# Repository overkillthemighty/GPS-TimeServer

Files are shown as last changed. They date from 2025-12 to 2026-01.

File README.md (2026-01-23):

# ESP32 PPS Time Server

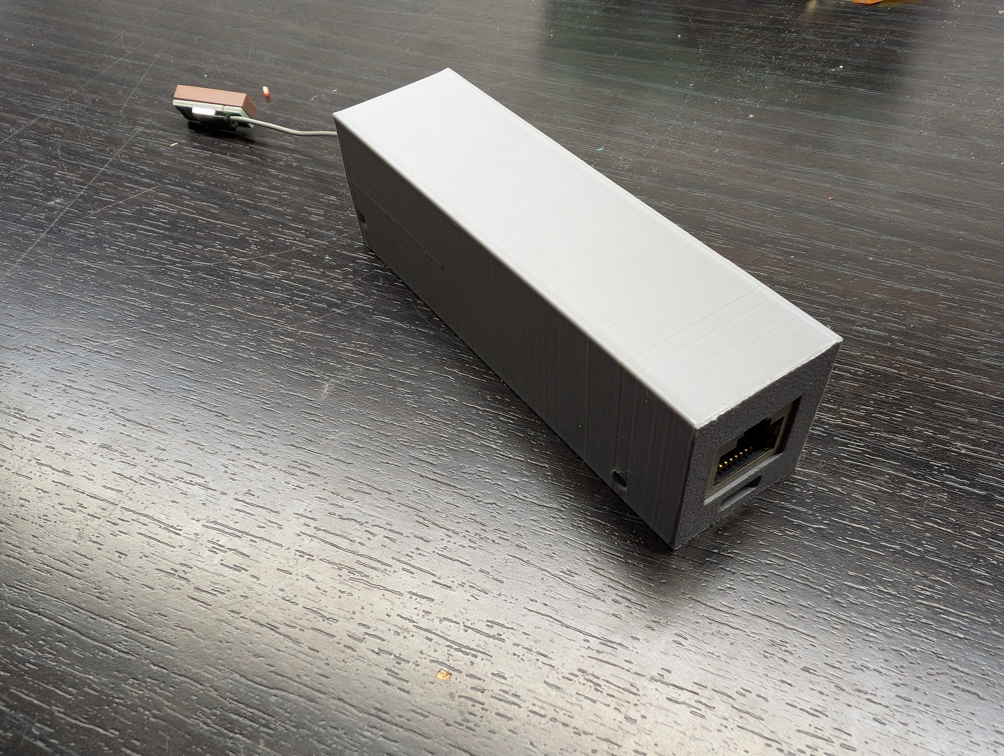
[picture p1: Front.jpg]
Assembled


I started this project when I was having trouble finding an ESP32-based PPS (Pulse Per Second) time server that compiled on a recent version of Arduino and had the features I wanted. This project provides a reliable, high-accuracy NTP server solution using an ESP32 with Ethernet support and Power over Ethernet (PoE).

## 🚀 Overview

This repository contains the firmware and 3D-printable housing for a Network Time Protocol (NTP) server. By utilizing the PPS signal from a GPS module, this server provides microsecond-level timing accuracy to your local network. 

The project is designed for the **Waveshare ESP32-S3-ETH**, but it should be easily adaptable to most ESP32 Ethernet boards and GPS modules with a PPS output.

## 🛠 Hardware Used

* **Microcontroller:** [Waveshare ESP32-S3-ETH](https://www.waveshare.com/esp32-s3-eth.htm) (Supports PoE)
* **GPS Module:** [Beitian BN-220 GPS/Glonass](https://a.co/d/dijGAva)
* **Power:** Runs directly off **PoE** via the Waveshare board, or can be powered via **USB-C**.

### Wiring Connections

| BN-220 GPS Pin | ESP32-S3-ETH Pin | Description |
| :--- | :--- | :--- |
| **VCC** | 3.3V or 5V | Power supply for GPS |
| **GND** | GND | Ground |
| **TX** | GPIO 18 (RX) | GPS Data Transmission |
| **RX** | GPIO 17 (TX) | GPS Data Reception |
| **PPS** | GPIO 2 | Pulse Per Second (High Precision) |

*Please verify these GPIO assignments in `ESP32TimeServer/ESP32TimeServer.ino` before powering on.*

## 📂 Project Structure

* **`/ESP32TimeServer`**: The Arduino sketch folder containing the source code.
* **`Case.stl`**: 3D-printable main housing for the electronics.
* **`LockBlock.stl`**: 3D-printable locking mechanism/mount.

## 🔧 Installation & Setup

1.  **Hardware:** Wire the BN-220 to the Waveshare board as shown in the table above.
2.  **Arduino IDE:** * Open `ESP32TimeServer.ino`.
    * Ensure the **ESP32 board manager** is installed (v2.0.x+).
    * Select **ESP32-S3 Dev Module** (or the specific Waveshare board profile if installed).
3.  **Flash:** Upload the code to the board via USB-C.
4.  **Enclosure:** Print the provided `.stl` files. The board is designed to snap into the case, secured by the LockBlock.

Note that I used Gemini quite a bit creating this.

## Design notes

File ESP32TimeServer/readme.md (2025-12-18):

# ESP32 MasterClock (Stratum-1 NTP via GPS PPS)

A professional-grade **ESP32-S3 + W5500** Ethernet device serving **UTC-only** NTP time as a Stratum‑1 source, disciplined by **GPS PPS**. 

This project is optimized for the **Waveshare ESP32-S3-ETH** development board and leverages the ESP32's dual-core architecture to ensure microsecond-level timing precision.

---

## 💻 Arduino IDE Configuration

To ensure compatibility with the board's 16MB Flash and PSRAM, use these exact settings in the **Tools** menu:

* **Board:** `ESP32-S3 Dev Module`
* **USB CDC On Boot:** `Enabled` (Required for the Serial Menu to work)
* **Flash Size:** `16MB (128Mb)`
* **Partition Scheme:** `16M Flash (3MB APP/9.9MB FATFS)`
* **PSRAM:** `OPI PSRAM`
* **Upload Speed:** `921600`

---

## 🚀 Key Features

### ⏱️ High-Precision Timing
- **Stratum-1 Source:** Synchronizes directly to GPS atomic clocks.
- **Dual-Core Execution:** - **Core 0:** Dedicated strictly to GPS NMEA parsing and high-priority PPS interrupt handling.
    - **Core 1:** Handles the Ethernet stack, NTP UDP requests, and the Web/Serial interfaces.
- **PPS Discipline:** RTC is corrected microsecond-by-microsecond upon every GPS pulse.

### 🌐 Networking & Reliability
- **Ethernet Only:** Wi-Fi and Bluetooth are disabled to eliminate radio-induced jitter and interrupt latency.
- **Smart Fallback:** Attempts DHCP on boot; if unsuccessful (10s timeout), falls back to the saved Static IP.
- **Serial Configuration Menu:** Full parity with the web interface for management via USB Serial.

---

## 🛠️ Hardware Setup

### Waveshare ESP32-S3-ETH Pinout
The default configuration in `ESP32TimeServerKeySettings.h` is mapped as follows:

| Component | Pin | Function |
| :--- | :--- | :--- |
| **GPS TX** | GPIO 17 | UART1 RX |
| **GPS RX** | GPIO 18 | UART1 TX |
| **GPS PPS** | GPIO 2 | Interrupt Pin |
| **ETH CS** | GPIO 14 | SPI Chip Select |
| **ETH RST** | GPIO 9 | Hardware Reset |
| **ETH IRQ** | GPIO 10 | Interrupt |

---

## ⌨️ Serial Menu Usage

Connect to the device via the Serial Monitor at **115200 baud**. Press **'h'** to see the command list:

* **`[s] Status`**: View current UTC time, GPS lock status, and satellite count.
* **`[i] Info`**: View active IP address and system uptime.
* **`[n] Network`**: **Configuration Wizard**. Use this to set Static IP, Gateway, and Subnet settings.
* **`[l] Logs`**: Dump the system event log from the internal ring buffer.
* **`[w] Wipe`**: Reset all network settings to factory defaults.
* **`[r] Reboot`**: Software restart.

---

## 📡 Required Libraries

Install these via the Arduino Library Manager:
1. `TinyGPSPlus` by Mikal Hart
2. `ESP32Time` by fbiego
3. `Time` by Paul Stoffregen

---

## 📄 License
MIT License — 2025. Created for high-reliability network time synchronization.

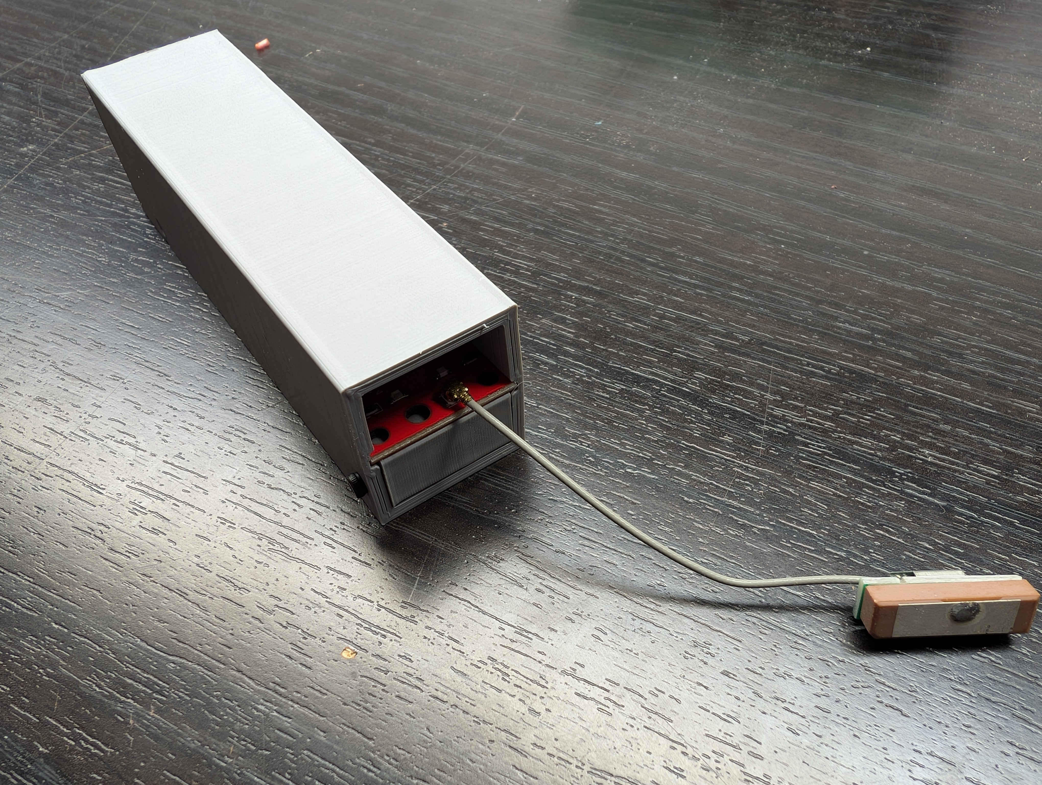
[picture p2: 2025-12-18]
Rear.jpg

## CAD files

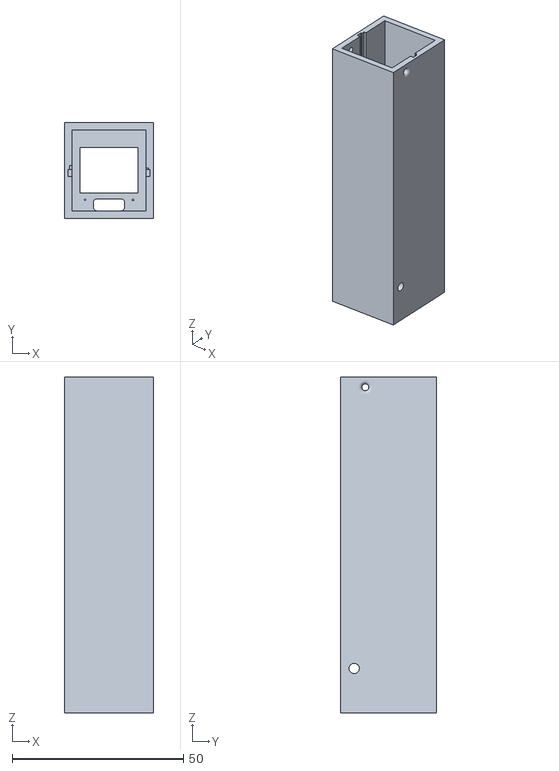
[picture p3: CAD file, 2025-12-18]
Case.stl
26.0 x 28.0 x 98.0

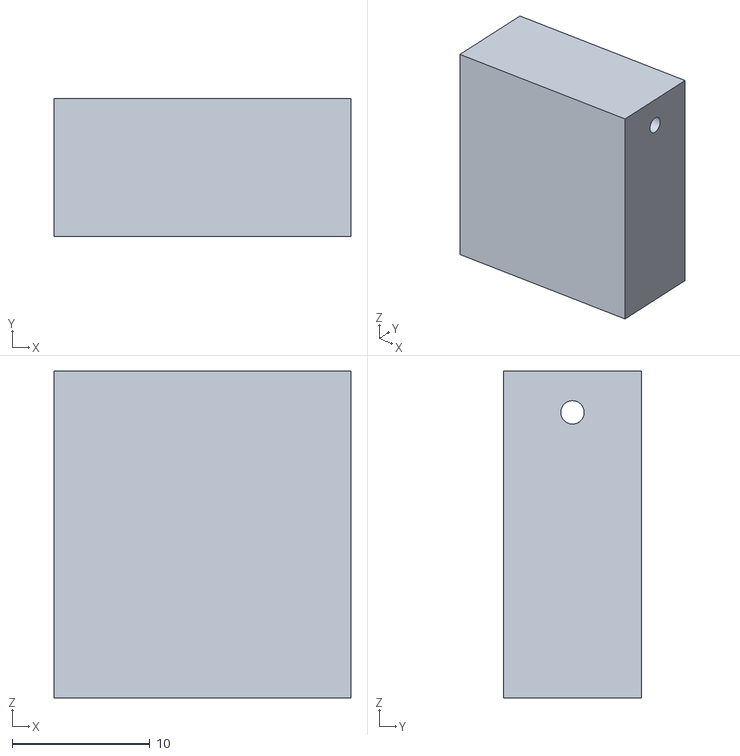
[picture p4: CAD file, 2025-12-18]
LockBlock.stl
21.5 x 10.0 x 23.7

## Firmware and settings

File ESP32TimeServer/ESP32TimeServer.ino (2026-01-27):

/*
Version 1.1
  ESP32TimeServer.ino
  MIT License — 2025

  Headless ESP32-S3 + W5500 NTP Stratum-1 server (UTC-only) using GPS PPS.

  - ETH-only (Wi-Fi and BT explicitly disabled)
  - Static IP or DHCP support
  - Serial Menu for Network Configuration (parity with Web UI)

  NTP reply fields implemented per RFC 5905 (NTPv4):
    - LI/VN/Mode = 0/4/4 when locked; LI=3, Stratum=16 when unsynchronized
    - Stratum, Poll, Precision set to sane values
    - Root Delay/Dispersion small non-zero fixed-point
    - Reference ID "GPS "
    - Timestamps (Reference/Originate/Receive/Transmit) are 64-bit:
        seconds since 1900-01-01 (NTP epoch) + 32-bit fractional part
*/
#include <ETH.h>
#include <SPI.h>
#include <WiFi.h>
#include <WiFiUdp.h>
#include <ESP32Time.h>
#include <TinyGPSPlus.h>
#include <TimeLib.h>
#include <WebServer.h>
#include <Update.h>
#include <Preferences.h>

#include "ESP32TimeServerKeySettings.h"

// ----------------- Ethernet pins / status -----------------
bool eth_connected = false;
bool eth_got_IP = false;
String ip = "";

// ----------------- Preferences & Config -------------------
Preferences prefs;
bool useStaticIP_Run = false;
IPAddress ip_Run, gw_Run, sn_Run, dns_Run;

// ----------------- Timekeeping ----------------------------
ESP32Time rtc(0);           // UTC
TinyGPSPlus gps;
HardwareSerial GPSDevice(1);

// PPS signalling
volatile bool ppsFlag = false;
portMUX_TYPE ppsMux = portMUX_INITIALIZER_UNLOCKED;

// ----------------- NTP -----------------
#define NTP_PACKET_SIZE 48
WiFiUDP Udp;
byte packetBuffer[NTP_PACKET_SIZE];
volatile uint64_t ntpServedCount = 0;

// ----------------- Guard rails / sync -----------------
volatile bool rtcTimeInitialized = false;
volatile bool SafeGuardTripped   = false;

// ----------------- freeRTOS / misc -----------------
SemaphoreHandle_t mutex;
TaskHandle_t gpsTaskHandle = NULL;
int gpsCoreID = -1;

// ----------------- Web Server Instance -----------------
WebServer server(WEB_PORT);
String   logRing[LOG_RING_CAPACITY];
size_t   logHead = 0;
size_t   logSize = 0;

// Jitter/offset stats
double lastUpdateDeltaSec = 0.0;
double ewmaOffsetSec      = 0.0;
double maxAbsOffsetSec    = 0.0;

// ----------------- Constants -----------------
const unsigned long oneSecond_inMs  = 1000UL;
const long          oneSecond_inUsL = 1000000L;
const double        oneSecond_inUsD = 1000000.0;

// ----------------- Helper (Used by Core, Web, and Serial) -----------------
void logMsg(const String& s) {
  if (xSemaphoreTake(mutex, portMAX_DELAY) == pdTRUE) {
    if (debugIsOn) Serial.println(s);
    logRing[logHead] = s;
    logHead = (logHead + 1) % LOG_RING_CAPACITY;
    if (logSize < LOG_RING_CAPACITY) logSize++;
    xSemaphoreGive(mutex);
  }
}

void GetUTC_DateAndTimeStrings(time_t UTC_Time, String &dateString, String &timeString) {
  dateString = String(year(UTC_Time));
  if (month(UTC_Time) < 10) dateString += "-0"; else dateString += "-";
  dateString += String(month(UTC_Time));
  if (day(UTC_Time) < 10) dateString += "-0"; else dateString += "-";
  dateString += String(day(UTC_Time));

  timeString  = (hour(UTC_Time)   < 10 ? "0" : "") + String(hour(UTC_Time));
  timeString += ":";
  timeString += (minute(UTC_Time) < 10 ? "0" : "") + String(minute(UTC_Time));
  timeString += ":";
  timeString += (second(UTC_Time) < 10 ? "0" : "") + String(second(UTC_Time));
}

// *** INCLUDE WEB HANDLER AFTER DEFINING GLOBALS ***
#include "WebServerHandler.h"

// ----------------- Serial Menu Logic -----------------
void processSerialMenu() {
  if (Serial.available() > 0) {
    char cmd = Serial.read();
    if (cmd == '\n' || cmd == '\r') return;

    Serial.println("\n--- Serial Command: " + String(cmd) + " ---");
    switch (cmd) {
      case 'h':
      case '?':
        Serial.println("Available Commands:");
        Serial.println(" [s] Status - Show current time & GPS stats");
        Serial.println(" [i] Info   - Show network & system info");
        Serial.println(" [n] Network- Configure IP settings (Wizard)");
        Serial.println(" [l] Logs   - Dump the system log buffer");
        Serial.println(" [r] Reboot - Restart device");
        Serial.println(" [w] Wipe   - Reset to factory defaults");
        break;

      case 'n': {
        Serial.println("--- Network Configuration Wizard ---");
        Serial.setTimeout(15000);
        Serial.print("Enter Static IP (e.g. 192.168.1.200): ");
        String s_ip = Serial.readStringUntil('\n'); s_ip.trim(); Serial.println(s_ip);
        Serial.print("Enter Gateway (e.g. 192.168.1.1): ");
        String s_gw = Serial.readStringUntil('\n'); s_gw.trim(); Serial.println(s_gw);
        Serial.print("Enter Subnet (e.g. 255.255.255.0): ");
        String s_sn = Serial.readStringUntil('\n'); s_sn.trim(); Serial.println(s_sn);
        Serial.print("Force Static IP? (y/n): ");
        String s_st = Serial.readStringUntil('\n'); s_st.trim(); Serial.println(s_st);

        IPAddress nIP, nGW, nSN;
        if (nIP.fromString(s_ip) && nGW.fromString(s_gw) && nSN.fromString(s_sn)) {
          prefs.begin("net_config", false);
          prefs.putBool("static", (s_st == "y" || s_st == "Y"));
          prefs.putUInt("ip",  (uint32_t)nIP);
          prefs.putUInt("gw",  (uint32_t)nGW);
          prefs.putUInt("sn",  (uint32_t)nSN);
          prefs.putUInt("dns", (uint32_t)IPAddress(8,8,8,8));
          prefs.end();
          Serial.println("Saved. Rebooting...");
          delay(1000);
          ESP.restart();
        } else {
          Serial.println("ERROR: Invalid IP format. Aborting.");
        }
        Serial.setTimeout(1000);
        break;
      }

      case 's': {
        String d, t;
        GetUTC_DateAndTimeStrings(rtc.getEpoch(), d, t);
        Serial.printf("Time: %s %s UTC \n Locked: %s\n",
                      d.c_str(), t.c_str(), rtcTimeInitialized ? "YES" : "NO");
        Serial.printf("Sats: %d \n HDOP: %.2f \n Guard: %s\n",
                      gps.satellites.value(), gps.hdop.value() / 100.0, SafeGuardTripped ? "TRIPPED" : "OK");
        break;
      }

      case 'i':
        Serial.println("IP: " + ip + " (" + (useStaticIP_Run ? "Static" : "DHCP") + ")");
        Serial.printf("Uptime: %lu s \n NTP Served: %llu\n", millis() / 1000UL, ntpServedCount);
        Serial.printf("Cores: GPS:%d / Sys:%d\n", gpsCoreID, xPortGetCoreID());
        break;

      case 'l':
        if (xSemaphoreTake(mutex, 100 / portTICK_PERIOD_MS) == pdTRUE) {
          size_t idx = (logSize == LOG_RING_CAPACITY) ? logHead : 0;
          for (size_t i = 0; i < logSize; ++i) {
            Serial.println(logRing[idx]);
            idx = (idx + 1) % LOG_RING_CAPACITY;
          }
          xSemaphoreGive(mutex);
        }
        break;

      case 'r': ESP.restart(); break;

      case 'w':
        prefs.begin("net_config", false); prefs.clear(); prefs.end();
        Serial.println("Settings wiped. Rebooting...");
        delay(500); ESP.restart();
        break;
    }
    Serial.println("-------------------------------");
  }
}

// ----------------- Core Logic -----------------
void turnOffWifiAndBluetooth() {
  WiFi.mode(WIFI_OFF);
  btStop();
}

void loadNetworkSettings() {
  prefs.begin("net_config", true);
  useStaticIP_Run = prefs.getBool("static", default_ForceStatic);

  auto loadIP = [&](const char* key, const uint8_t* def) -> IPAddress {
    uint32_t val = prefs.getUInt(key, 0);
    if (val == 0) return IPAddress(def);
    return IPAddress(val);
  };
  ip_Run  = loadIP("ip",  default_ip);
  gw_Run  = loadIP("gw",  default_gw);
  sn_Run  = loadIP("sn",  default_sn);
  dns_Run = loadIP("dns", default_dns);
  prefs.end();
}

void setupSerial() {
  Serial.begin(SerialMonitorSpeed);
  if (debugIsOn) {
    delay(300);
    Serial.println();
    Serial.println("Type h for a list of commands.");
    Serial.println("ESP32 Time Server starting setup ...");
  }
}

void setupGPS() {
  GPSDevice.begin(GPSBaud, SERIAL_8N1, RXPin, TXPin);
  delay(100);
  logMsg("GPS UART initialized at " + String(GPSBaud) + " baud.");
}

void IRAM_ATTR ppsHandlerRising() {
  portENTER_CRITICAL_ISR(&ppsMux);
  ppsFlag = true;
  portEXIT_CRITICAL_ISR(&ppsMux);
}

static inline bool gpsDataValidNow() {
  return gps.date.isValid() && gps.time.isValid()
      && gps.location.isValid() && gps.location.age() < 1000
      && gps.satellites.isValid() && gps.satellites.value() >= 4;
}

void setDateAndTimeFromGPS(void* parameter) {
  const double guardLow  = -safeguardThresholdSeconds;
  const double guardHigh =  safeguardThresholdSeconds;
  bool firstSet = true;
  int  consecutiveFailures = 0;
  gpsCoreID = xPortGetCoreID();

  for (;;) {
    // Drain any stale bytes
    while (GPSDevice.available() > 0) { GPSDevice.read(); }

    // Wait until we have valid, fresh GPS data
    while (!gpsDataValidNow()) {
      while (GPSDevice.available() > 0) { gps.encode(GPSDevice.read()); }
      vTaskDelay(10 / portTICK_PERIOD_MS);
    }

    // Wait up to ~1.1s for PPS edge
    ppsFlag = false;
    unsigned long ppsStart = millis();
    while (millis() - ppsStart < 1100) {
      if (ppsFlag) break;
      vTaskDelay(1);
    }

    // Build candidate UTC from GPS
    struct tm wt;
    wt.tm_year = gps.date.year();
    wt.tm_mon  = gps.date.month();
    wt.tm_mday = gps.date.day();
    wt.tm_hour = gps.time.hour();
    wt.tm_min  = gps.time.minute();
    wt.tm_sec  = gps.time.second();
    wt.tm_year -= 1900;   // tm is years since 1900
    wt.tm_mon  -= 1;      // tm_mon is 0..11
    time_t candidate = mktime(&wt);
    // Align to the start of the second after PPS
    candidate += 1;

    // Peg microsecond timing around the set
    unsigned long pegStartUs = micros();

    bool okToUpdate = true;
    double updateDelta = 0;
    if (!firstSet) {
      time_t currentRTC_t = rtc.getEpoch();
      updateDelta = (double)currentRTC_t - (double)candidate;
      okToUpdate = (updateDelta >= guardLow && updateDelta <= guardHigh);
    }

    if (okToUpdate) {
      if (xSemaphoreTake(mutex, portMAX_DELAY) == pdTRUE) {
        unsigned long pegEndUs = micros();
        long finalMicros = (long)(pegEndUs - pegStartUs) + (RTCLatencyCorrectionMs * 1000L);
        rtc.setTime((uint32_t)candidate, (int)finalMicros);

        lastUpdateDeltaSec = updateDelta;
        ewmaOffsetSec = (firstSet ? 0.0 : (0.2 * fabs(updateDelta) + 0.8 * ewmaOffsetSec));
        xSemaphoreGive(mutex);
      }
      SafeGuardTripped   = false;
      firstSet           = false;
      rtcTimeInitialized = true;

      vTaskDelay(periodicTimeRefreshPeriodMs / portTICK_PERIOD_MS);
    } else {
      SafeGuardTripped = true;
      vTaskDelay(1000 / portTICK_PERIOD_MS);
    }
  }
}

void EthEvent(WiFiEvent_t event) {
  switch (event) {
    case ARDUINO_EVENT_ETH_START:      ETH.setHostname(ETH_HOSTNAME); break;
    case ARDUINO_EVENT_ETH_CONNECTED:  eth_connected = true;           break;
    case ARDUINO_EVENT_ETH_GOT_IP:
      eth_got_IP = true; ip = ETH.localIP().toString();
      logMsg("ETH IP: " + ip); break;
    case ARDUINO_EVENT_ETH_DISCONNECTED: eth_connected = false; eth_got_IP = false; break;
    default: break;
  }
}

bool setupEitherNetWithRetry() {
  SPI.begin(ETH_SPI_SCK, ETH_SPI_MISO, ETH_SPI_MOSI);
  WiFi.onEvent(EthEvent);

  pinMode(ETH_PHY_RST, OUTPUT);
  digitalWrite(ETH_PHY_RST, LOW);  delay(10);
  digitalWrite(ETH_PHY_RST, HIGH); delay(10);

  ETH.begin(ETH_PHY_TYPE, ETH_PHY_ADDR, ETH_PHY_CS, ETH_PHY_IRQ, ETH_PHY_RST, SPI);
  if (useStaticIP_Run) ETH.config(ip_Run, gw_Run, sn_Run, dns_Run);

  unsigned long t0 = millis();
  while (!eth_got_IP && (millis() - t0) < 10000UL) delay(10);

  if (!eth_got_IP && !useStaticIP_Run) {
    // Fall back to default static configuration if DHCP failed
    ETH.config(ip_Run, gw_Run, sn_Run, dns_Run);
    t0 = millis();
    while (!eth_got_IP && (millis() - t0) < 8000UL) delay(10);
  }
  return eth_got_IP;
}

/* ===================== NTP helpers & server reply ===================== */

// Write big-endian 32-bit
static inline void write_u32_be(uint8_t* p, uint32_t v) {
  p[0] = (uint8_t)(v >> 24);
  p[1] = (uint8_t)(v >> 16);
  p[2] = (uint8_t)(v >> 8);
  p[3] = (uint8_t)(v);
}

// Write NTP 64-bit timestamp (seconds + fraction)
static inline void write_ntp_ts(uint8_t* p, uint32_t sec, uint32_t frac) {
  write_u32_be(p,     sec);
  write_u32_be(p + 4, frac);
}

// Build current time in NTP epoch (seconds since 1900) + 32-bit fraction
static inline void ntp_now(uint32_t& sec, uint32_t& frac) {
  const uint32_t NTP_DELTA = 2208988800UL;         // UNIX->NTP seconds
  uint32_t unixSec = (uint32_t)rtc.getEpoch();
  uint32_t usec    = (uint32_t)(rtc.getMicros() % 1000000UL);
  sec  = unixSec + NTP_DELTA;
  // fraction = usec / 1e6 * 2^32  =>  usec * 4294.967296
  frac = (uint32_t)((double)usec * 4294.967296);
}

void processNTPRequests() {
  int packetSize = Udp.parsePacket();
  if (packetSize <= 0) return;

  // Read request (ignore >48 extra bytes if any)
  uint8_t req[NTP_PACKET_SIZE];
  int r = Udp.read(req, NTP_PACKET_SIZE);
  if (r < 48) return; // not an NTP request

  if (xSemaphoreTake(mutex, portMAX_DELAY) == pdTRUE) {
    uint8_t rsp[NTP_PACKET_SIZE] = {0};

    // Snapshot server receive time as soon as possible
    uint32_t rcv_s, rcv_f;
    ntp_now(rcv_s, rcv_f);

    // 1) LI/VN/Mode
    bool synced = rtcTimeInitialized && !SafeGuardTripped;
    uint8_t LI   = synced ? 0 : 3;    // 0=no warning, 3=unsynchronized
    uint8_t VN   = 4;                 // NTPv4
    uint8_t MODE = 4;                 // server
    rsp[0] = (uint8_t)((LI << 6) | (VN << 3) | MODE);

    // 2) Stratum, Poll, Precision
    rsp[1] = synced ? 1 : 16;         // Stratum 1 when locked; 16 (unsynced)
    rsp[2] = 4;                       // Poll interval (2^4 = 16 s nominal)
    rsp[3] = (uint8_t)-20;            // Precision ~2^-20 s (~1 µs)

    // 3) Root Delay/Dispersion (16.16 fixed point). Small non-zero values.
    write_u32_be(&rsp[4],  0x00010000);   // 1.0 s
    write_u32_be(&rsp[8],  0x00010000);   // 1.0 s

    // 4) Reference ID for stratum-1 (ASCII)
    rsp[12] = 'G'; rsp[13] = 'P'; rsp[14] = 'S'; rsp[15] = ' ';

    // 5) Reference Timestamp (when we last set/confirmed time) - use now
    uint32_t ref_s, ref_f;
    ref_s = rcv_s; ref_f = rcv_f;
    write_ntp_ts(&rsp[16], ref_s, ref_f);

    // 6) Originate: copy client's Transmit (req bytes 40..47)
    memcpy(&rsp[24], &req[40], 8);

    // 7) Receive (server receive timestamp)
    write_ntp_ts(&rsp[32], rcv_s, rcv_f);

    // 8) Transmit (server transmit timestamp — just before send)
    uint32_t xmt_s, xmt_f;
    ntp_now(xmt_s, xmt_f);
    write_ntp_ts(&rsp[40], xmt_s, xmt_f);

    // Send reply
    Udp.beginPacket(Udp.remoteIP(), Udp.remotePort());
    Udp.write(rsp, NTP_PACKET_SIZE);
    Udp.endPacket();

    ntpServedCount++;
    xSemaphoreGive(mutex);
  }
}

/* ===================== end NTP helpers & server reply ===================== */

void setup() {
  setupSerial();
  mutex = xSemaphoreCreateMutex();

  loadNetworkSettings();
  turnOffWifiAndBluetooth();

  pinMode(PPSPin, INPUT_PULLUP);
  attachInterrupt(digitalPinToInterrupt(PPSPin), ppsHandlerRising, RISING);

  setupGPS();
  xTaskCreatePinnedToCore(setDateAndTimeFromGPS, "GPS", 3072, NULL, 20, &gpsTaskHandle, 0);

  // Optional: wait up to 30s for first RTC lock
  unsigned long t0 = millis();
  while (!rtcTimeInitialized && (millis() - t0) < 30000UL) delay(10);

  if (setupEitherNetWithRetry()) {
    Udp.begin(NTP_PORT);
    startWeb();
    Serial.println("\nSystem Ready. Type 'h' for menu.");
  }
}

void loop() {
  processNTPRequests();
  processWebLoop();
  processSerialMenu();

}

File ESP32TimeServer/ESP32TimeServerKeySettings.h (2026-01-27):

#pragma once // <--- CRITICAL: Prevents redefinition errors

// ESP32TimeServerKeySettings.h
// MIT License — 2025
// Project key settings (pins, speeds, toggles). Keep this file device-specific.

// versioning
const char* FIRMWARE_VERSION = "1.1";

// ---------- Serial / Debug ----------
const int  SerialMonitorSpeed = 115200;
const bool debugIsOn          = true;      // set false for production

// ---------- GPS (UART1) ----------
const int RXPin   = 17;              // GPS TX -> ESP32 RXPin
const int TXPin   = 18;              // GPS RX -> ESP32 TXPin
const int PPSPin  = 2;               // PPS input pin
const uint32_t GPSBaud = 9600;       // NEO-6M default baud

// ---------- Ethernet (W5500 via SPI) ----------
#define ETH_PHY_TYPE  ETH_PHY_W5500
#define ETH_PHY_ADDR  1
#define ETH_PHY_CS    14
#define ETH_PHY_IRQ   10
#define ETH_PHY_RST    9
#define ETH_SPI_SCK   13
#define ETH_SPI_MISO  12
#define ETH_SPI_MOSI  11

// Hostname (ETH)
const char* ETH_HOSTNAME = "GPS-NTP";

// ---------- Network Configuration (Defaults) ----------
const bool default_ForceStatic = false; // If false, tries DHCP first, then falls back to Static
// Default Static / Fallback Settings
const uint8_t default_ip[4]   = { 192, 168, 1, 200 };
const uint8_t default_gw[4]   = { 192, 168, 1, 1 };
const uint8_t default_sn[4]   = { 255, 255, 255, 0 };
const uint8_t default_dns[4]  = { 8, 8, 8, 8 };

// ---------- NTP ----------
const uint16_t NTP_PORT = 123;

// ---------- Time refresh / guard rails ----------
const unsigned long periodicTimeRefreshPeriodMs = 15UL * 1000UL; // refresh from GPS every 15s
const double safeguardThresholdSeconds         = 0.20;           // +/- 200ms sanity window
const long RTCLatencyCorrectionMs = 0;

// ---------- Web ----------
const uint16_t WEB_PORT               = 80;
const size_t   LOG_RING_CAPACITY      = 200;     // last N log entries served via web
const bool     webEnabled             = true;    // can disable if you want ultra-lean

const bool     otaEnabled             = true;    // HTTP upload firmware via /update

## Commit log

2025-12-18 Initial Upload
    [Case.stl, LockBlock.stl]
2026-01-23 Update README.md
    Wrong Pin Defs
2026-01-27 Fixed bug where server returned time of client
    [ESP32TimeServer.ino]
2026-01-27 Update ESP32TimeServerKeySettings.h
    Changed Version
2026-01-27 Update ESP32TimeServerKeySettings.h
    Set Version number across files
2026-01-27 Update ESP32TimeServer.ino
    Set version number
